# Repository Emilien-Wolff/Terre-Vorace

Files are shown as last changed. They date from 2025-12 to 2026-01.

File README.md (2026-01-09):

# Commande entreprise - solutions d'aération d'un lombricomposteur 🪱
> [!NOTE]
> Un projet dans le cadre de ma deuxième année en école d'ingénieur visant l'élaboration d'une aération d'un lombricomposteur pour préserver les lombrics



## Objectifs

> Améliorer le composteur en le dotant d’un système d’aération efficace permettant la survie des lombrics.

> Permettre une régulation de l’humidité dans l’enceinte du lombricomposteur, sans dépasser un certain seuil.

## Points abordés

 - Gestion de projet : diagramme de Gantt, partage des tâches et planification tout au long du projet
 - Etude thermodynamique : dimensionnement paramétrique de l'installation en fonction de la taille des ouvertures nécessaire, flux, aération forcée ou non, ...
 - Code et montage d'un capteur hygrométrique pour les tests
 - Réalisation : fabrication des solutions techniques et implantation sur lombricomposteurs
 - Rapports au client

## FAQ

#### Qu'est ce que Terre Vorace ?

Terre Vorace est une entreprise française (basée à Nantes) spécialisée dans la gestion des biodéchets pour les structures professionnelles (B2B). Elle propose une solution clé en main de valorisation des biodéchets via le lombricompostage, en installant chez ses clients des composteurs connectés et éco-conçus qui transforment ces déchets en engrais organique utile, tout en assurant un suivi numérique des opérations et des données RSE. L’objectif est de minimiser l’impact environnemental, de réduire les coûts et de faciliter la conformité réglementaire pour les entreprises, écoles ou espaces de coworking qui souhaitent valoriser localement leurs biodéchets.

#### Combien de temps ça vous a pris ?

Le projet a duré 3 mois, de septembre 2025 à  fin novembre 2025

## 🚀 Qui suis-je ?
Je suis actuellement étudiant ingénieur automaticien en deuxième année d'école d'ingénieur à l'école des Mines IMT Atlantique.

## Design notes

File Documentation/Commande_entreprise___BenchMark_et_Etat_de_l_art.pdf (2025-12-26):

X

Benchmark - GROUPE 60
Projet Commande Entreprise - parcours ingénieur A2 FISE

## Projet Commande Entreprise :

## Système d’aération d’un milieu fermé

## en lombricompostage autonome

Destinataires : FRISCOURT François, D’HERBEMONT Arthur Relecteurs : RABIER Valentin

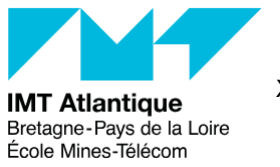
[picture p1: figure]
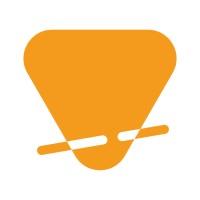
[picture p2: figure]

Date d’édition : 23 octobre 2025 Version : V2

Wolff Emilien

Gerbaud Paul

Albert Louis
Kayser Valentin
Rabier Valentin

Rouyre Sarah
Adam Raphaël

Ribeiro de Assis Nathalia

Tuteur école : D’Herbemont Arthur Tuteur entreprise : Friscours François

IMT Atlantique
Projet Commande Entreprise
Campus de Nantes — IMT Atlantique 4, rue Alfred Kastler — La Chantrerie CS 20722
44307 Nantes Cedex 3
Téléphone : +33 (0)2 51 85 81 00 URL : www.imt-atlantique.fr

Liste des tableaux

### Sommaire

1. Introduction et cahier des charges du projet | 2
2. Benchmark et Etat de l’Art | 4
2.1. Solutions possibles et coût prévisionnel de chacune d’entres elles | | 4
2.1.1. Solution A – Evacuation d’air dans les coins | | 4
2.1.2. Solution B – Tube d’aération unique placé au centre du compost | | 6
2.1.3. Solution C – Ventilation Forcée | | 9
2.1.4. Solution D – Agitation Mécanique | 12
3. Conclusion | 14

### 3.1. Comparaison des solutions entre elles et adéquation avec le cahier des charges | 14

Annexes | 15
Références | 16

### Liste des figures

2.1. Schéma de la solution A | | 4
2.2. Schéma de la solution B | | 6
2.3. Schéma de la solution B | | 9
2.4. Schéma de la solution D | 12

### Liste des tableaux

1.1. Tableau des fonctionnalités, critères, niveaux, flexibilité et priorité pour le projet Terre Vorace.
FP : fonction principale, FS : fonction secondaire, FC : fonction de contrainte | | 3
2.1. Estimation des coûts matière, usinage et membrane pour le tube d’aération latéral, en euros . | 5
2.2. Estimation des coûts matière, usinage et membrane pour le tube d’aération central | | 7
2.3. Estimation des coûts matière, usinage et ventilateur pour la solution C : ventilation forcée. . 10
2.4. Estimation des coûts matière, usinage (solution D) | 13
3.1. Comparaison des solutions A–D selon les critères du cahier des charges | 14
Synthèse de projet | 1/16

## Chapitre 1

# Introduction et cahier des charges du projet

Ce document a pour but de citer les différentes solutions possibles pour aérer efficacement un lombricomposteur. Ces solutions ont été trouvé et établies grâce à des recherches documentaires, et adaptée afin de remplir les exigences établies dans le précédent document. On rappelle ci-après le cahier des charges du projet, ainsi que les objectifs du projet.

En parallèle, une première modélisation physique du système a été effectuée. Le document complet est disponible ci-dessous :
→ Consulter le rapport de modélisation physique du système (PDF)

OBJECTIF

1. Améliorer le composteur en le dotant d’un système d’aération efficace permettant la survie des lombrics.
2. Permettre une régulation de l’humidité dans l’enceinte du lombricomposteur, sans dépasser un certain seuil.

2

Fonction | Critère(s) | Niveau(x) | Flexibilité | Priorité
FP1 – Maintenir un environnement favo-rable aux lombrics | Température interne | ≤ 30◦C (idéal 25°C) | Faible | 1
| Humidité de l’air de la boite | 60–80% | Faible
| Protection contre gel et cha-leur extrême | Tolérance au froid, max 35°C ambiant | Nulle
FP2 – Assurer une ventilation et évacua-tion d’humidité | Débit d’air suffisant | Limiter condensa-tion | Moyenne | 1
| Filtration des odeurs | Aucune odeur à proximité du lombri-composteur (détectable par un nez humain) | Faible
| Étanchéité aux nuisibles | Aucun insecte ni lombric ne passe | Nulle
FS1 – Assurer une autonomie énergé-tique low-tech | Source d’énergie | Piles privi-légiées (pas solaire/piezo) | Moyenne | 2
| Consommation énergétique | Très faible, sys-tème passif fa-vorisé | Forte
FS2 – Assurer un ré-trofit sur des lom-bricomposteurs exis-tants | Simplicité d’installation | Adaptation simple sur lom-bricomposteur existant (-d’1 h) | Moyenne | 1
FC1 – Respecter les contraintes maté-riaux et production | Matériaux | Prototype en bois/imprimé en 3D ; Solu-tion finale en matière recyclé et/ou (métal possible) et/ou bois | Moyenne | 1
| Budget prototypage | ≤ 1000€ | Nulle
FC2 – Assurer une évacuation simple du compost par le tech-nicien | Espace disponible | Aisance d’uti-lisation d’une pelle au sein du lombricom-posteur | Faible | 1
FC3 – Transportabi-lité | Masse totale vide | ≈ 60 kg max | Moyenne | 3

Table 1.1 – Tableau des fonctionnalités, critères, niveaux, flexibilité et priorité pour le projet Terre Vorace. FP : fonction principale, FS : fonction secondaire, FC : fonction de contrainte.

## Chapitre 2

# Benchmark et Etat de l’Art

Cette section présente les différentes solutions analysées dans le cadre du benchmark. Chaque solution est décrite selon des critères afin de permettre une comparaison objective.

### 2.1. Solutions possibles et coût prévisionnel de chacune d’entres elles

### 2.1.1. Solution A – Evacuation d’air dans les coins

■ | Nom de la solution : Evacuation dans les coins
■ | Exigences du CDCF : Toutes
■ | Matériaux envisagés : PVC, Métal (aluminium), Impression 3D

Schéma de la solution :

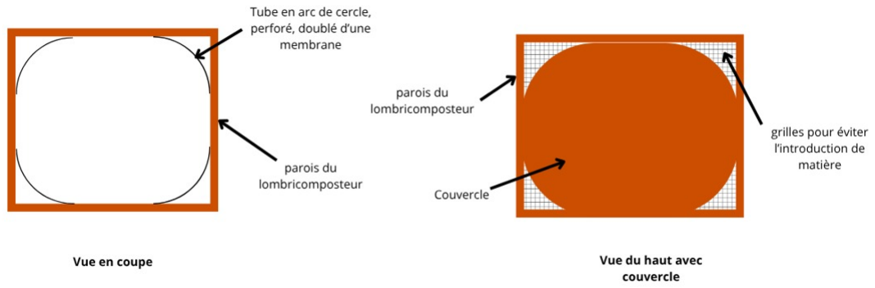
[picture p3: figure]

Figure 2.1 – Schéma de la solution A

Description générale :

Implémentation de tubes en arc de cercle perforés dans les coins du lombricomposteur. Les tubes seront doublés avec une membrane pour éviter le passage des vers ou d’acariens. Le flux d’air principal passera donc dans le coin, entre la paroi du lombricomposteur et le tube. Pour faciliter son passage, le couvercle et le bas du lombricomposteur recouvriront seulement la partie où il y a la matière compostable. Les trous laissés seront recouverts de grillage ou d’une membrane protectrice pour éviter l’introduction de matière à cet endroit.

Fonctionnalités principales :

■ | Gestion du taux d’humidité et de la température dans le composteur
■ | Intégration simple aux composteurs déjà existants
| 4

2.1. Solutions possibles et coût prévisionnel de chacune d’entres elles

Tarification :

On suppose que l’on achètera un tube de 70 cm de long, et de 300 mm de diamètre, que l’on coupe en 4. Chacune des pièces obtenues sera alors insérée dans un coin du lombricomposteur

Dans le cas du PVC :

■ Achat du PVC en magasin de bricolage
■ Usinage par un opérateur (cout de la machine de découpage non inclu)

Dans le cas de l’aluminium recyclé :
Volume de matière nécessaire = Aire de la section de paroi × longueur = π ·(150² −145² )· 0.70 ≈ 0.003245m³
Or la densité de l’aluminium est environ de 2700 kg/m³
Donc la masse d’aluminium nécessaire par tube est de 8.76 kg.
On prend un prix d’aluminium recyclé autour de 1.8 euros par kg (si fabrication d’une cinquantaine de tubes) On ajoute ensuite le coût d’usinage entre 25 à 30 euros par tube.

Dans le cas de l’impression 3D :

Le même volume de matière est nécessaire que dans le cas de l’aluminium. Le prix de la matière est de 25 euros au kilo.
Le cout d’usinage est moindre car on considère la machine déjà amortie, et on usine par quart de tube, donc pas de découpe nécessaire. Les seuls frais associés est celui des employés devant lancés l’imprimante à intervalles réguliers.

Membrane ventilante à coller à l’intérieur du tube

Il faut une membrane microporeuse / perméable à l’air (par exemple membrane PTFE, membrane respirante...) collée ou fixée à l’intérieur du tube pour laisser passer l’air mais limiter le passage de matières solides ou vers. On prend une estimation de coût de membrane à ∼ 0.25 euros/m²
La surface de membrane nécessaire serait l’aire latérale intérieure du tube :
| Amembrane = π d L ≈ π × 0,096 × 0,700 ≈ 0,211 m²

Donc coût membrane :

| Cmembrane ≈ 0,211 × 0,25 = 0.053€

On peut arrondir selon condition de commande, adhésif, découpe, etc. Disons 0,10€ à 0,20€. Coût des matériaux :

Matériau | Coût matière | Usinage estimé | Membrane | Total estimé
PVC | 25€ | 8€ | 0,10€ | 34€
Aluminium | 13€ | 25€ à 30€ | 0,10€ | 40€ à 45€
Impression 3D | 8€ | 5€ à 10€ | 0.10€ | 20€ à 25€

Table 2.1 – Estimation des coûts matière, usinage et membrane pour le tube d’aération latéral, en euros

Avantages :

■ | Facile à mettre en place
■ | Entretien facilité par les angles

Limites :

■ | Etanchéité aux extrémités des tubes à vérifier
■ | Efficacité faible au centre de compost (voir si cette solution s’avère efficace ou non)

### 2.1.2. Solution B – Tube d’aération unique placé au centre du compost

■ | Nom de la Solution [Tube d’aération placé au centre du compost]
■ | Exigences du CDCF : [Toutes]
■ | Matériaux envisagés : PVC, Métal (aluminium, acier), Impression 3D

Schéma de la solution :

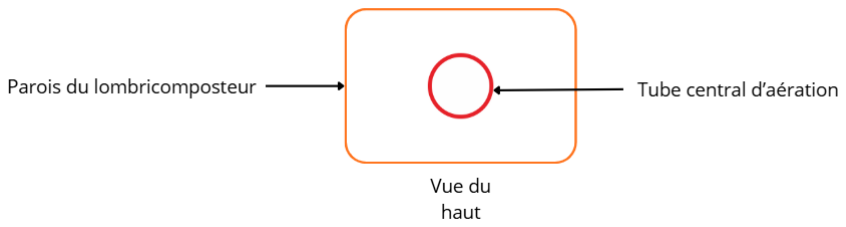
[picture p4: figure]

Figure 2.2 – Schéma de la solution B

Description générale :

Implémentation d’un tube d’aération unique en plein centre du lombricomposteur, muni d’une aération latérale à l’aide de trous percés, ainsi que d’une couche membranique afin d’éviter que les vers ne tombent dans le tuyau ou l’introduction d’acariens. Le tube sera démontable afin de faciliter l’entretien du lombricomposteur, la base restera au fond du composteur est fera la hauteur de la litière des vers. Il sera facilement replaçable (grâce à un système de clip ou de vissage avec la base).

Fonctionnalités principales :

■ | Gestion du taux d’humidité et de la température dans le composteur
■ | Intégration simple aux composteurs déjà existants

Estimation de coût d’un tube d’aération central avec membrane

Hypothèses géométriques

On prend les hypothèses suivantes :

■ | Le tube est de longueur L = 700 mm = 0,700 m.
■ | Diamètre extérieur D = 100 mm = 0,100 m.
■ | Épaisseur de paroi t = 2 mm = 0,002 m.
■ | Diamètre intérieur d = D − 2t = 0,100 − 2 × 0,002 = 0,096 m.

Le volume de matériau est donc :

| V = π · D² − d
| 2
| 4 · L = π · (0,100)² − (0,096)²
| 4 · 0,700 ≈ 0,0004305 m³

On note les densités approximatives :

■ Acier (acier simple) : ρacier = 7 800 kg/m³
■ Aluminium : ρalu = 2 700 kg/m³
■ | PVC rigide : ρPVC = 1 400 kg/m³ (valeur indicative).

Les masses estimées :

macier = ρacier · V ≈ 7 800 × 0,0004305 ≈ 3,36 kg,

malu = 2 700 × 0,0004305 ≈ 1,16 kg,

mPVC = 1 400 × 0,0004305 ≈ 0,60 kg.

Coût matière estimé

Pour le prix unitaire des matières, on prend des estimations raisonnables (à ajuster selon les fournisseurs) :

■ Acier : 1,0 €/kg
■ Aluminium : 2,6 €/kg(valeur souvent citée pour l’aluminium neuf)
■ PVC rigide : 1,5 €/kg

Donc les coûts matière :

Cmatière, acier ≈ 3,36 × 1,0 = 3,36 €

Cmatière, alu ≈ 1,16 × 2,6 = 3,02 €

Cmatière, PVC ≈ 0,60 × 1,5 = 0,90 €

Coût d’usinage / fabrication

On ajoute une estimation pour l’usinage, la découpe, l’assemblage, la finition, selon matériau :

■ Acier : 15€ à 25€
■ Aluminium : 25€ à 30€
■ PVC : 4€ à 8€

Membrane ventilante à coller à l’intérieur du tube

Même calcul que dans la solution A.

Coût total estimé

On met tout ensemble :

Ctotal = Cmatière + Cusinage + Cmembrane.

Matériau | Coût matière | Usinage estimé | Membrane | Total estimé
Acier | ≈ 3,36 € | 15 à 25 € | ∼ 0,10 € | ∼ 18,5 à 28,5 €
Aluminium | ≈ 3,02 € | 25 à 30 € | ∼ 0,10 € | ∼ 28,1 à 33,1 €
PVC | ≈ 0,90 € | 4 à 8 € | ∼ 0,10 € | ∼ 5,0 à 9,0 €

Table 2.2 – Estimation des coûts matière, usinage et membrane pour le tube d’aération central.

Discussion et remarques

■ | Ces estimations dépendent fortement des coûts locaux d’atelier, des quantités, frais de transport, de l’adhésif de membrane, etc.
■ | L’usinage de l’aluminium (soudure ou assemblage) peut être plus coûteux que pour l’acier selon les compétences de l’atelier.
■ | Le PVC est le moins cher mais est moins résistant mécaniquement, et la membrane devra bien adhérer (étanchéité, collage) pour durer dans le temps.
■ | On pourrait envisager une version avec tube plus gros (diamètre extérieur de 120 mm, épaisseur 3 mm), cela augmenterait les coûts proportionnellement au volume.
■ | Si on utilise de l’acier inoxydable, le coût matière pourrait être bien plus élevé.
■ | Le coût de membrane est négligeable comparé au coût matière + usinage dans ces dimensions, mais il faut prévoir adhésifs, découpe, manutention.

Avantages :

■ Aération efficace au centre du compost
■ Entretien facile car le tube est démontable

Limites :

■ | Etanchéité aux extrémités des tubes à vérifier
■ | Etanchéité aux niveau des attaches du tube à vérifier
■ | Perte de volume utile important en fonction de la taille du tube

### 2.1.3. Solution C – Ventilation Forcée

■ | Nom de la Solution [Tube d’aération placé au centre du compost avec aération forcée]
■ | Exigences du CDCF : [Toutes]
■ | Matériaux envisagés : PVC, Métal (aluminium, acier), Impression 3D, ventillateur acheté complet

SCHEMA DE LA SOLUTION :

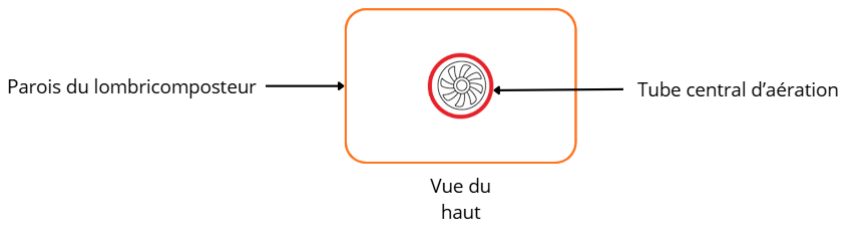
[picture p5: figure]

Figure 2.3 – Schéma de la solution B

Description générale :

La solution consiste à intégrer à nouveau un tube d’aération unique en plein centre du lombricomposteur, muni d’une aération latérale à l’aide de trous percés, ainsi que d’une couche membranique afin d’éviter que les vers ne tombent dans ce même trou. On ajoute un système de ventilation forcée à faible consommation. Ce petit ventilateur, placé sur la partie supérieure ou inférieure du lombricomposteur crée un flux d’air forcé qui augmente l’éfficacité du tube seul.

Fonctionnalités principales :

■ | Gestion du taux d’humidité et de la température dans le composteur
■ | Intégration simple aux composteurs déjà existants

Estimation de coût de la Solution C – Ventilation forcée

Hypothèses géométriques

On prend les mêmes hypothèses géométriques que pour la Solution B afin de garder une cohérence de comparaison :

■ | Longueur du tube L = 700 mm = 0,700 m
■ | Diamètre extérieur D = 100 mm = 0,100 m
■ | Épaisseur de paroi t = 2 mm = 0,002 m
■ | Diamètre intérieur d = D − 2t = 0,100 − 2 × 0,002 = 0,096 m

Le volume du matériau est donc :

| V = π · D² − d
| 2
| 4 · L = π · (0,100)² − (0,096)²
| 4 · 0,700 ≈ 0,0004305 m³

Densités approximatives :
■ Acier (acier simple) : ρacier = 7 800 kg/m³ ■ Aluminium : ρalu = 2 700 kg/m³
■ PVC rigide : ρPVC = 1 400 kg/m³

Masses estimées :

macier = 7 800×0,0004305 ≈ 3,36 kg, | malu = 2 700×0,0004305 ≈ 1,16 kg, | mPVC = 1 400×0,0004305 ≈ 0,60 kg.

Coût matière estimé

Prix unitaires estimés (à affiner selon fournisseurs) :

■ Acier : 1,0 €/kg
■ Aluminium : 2,6 €/kg (valeur moyenne de l’aluminium neuf) ■ PVC rigide : 1,5 €/kg

Donc les coûts matière :

Cmatière, acier ≈ 3,36 × 1,0 = 3,36 €

Cmatière, alu ≈ 1,16 × 2,6 = 3,02 €

Cmatière, PVC ≈ 0,60 × 1,5 = 0,90 €

Coût d’usinage / fabrication

On ajoute une estimation pour la découpe, le perçage, l’assemblage et la fixation du ventilateur selon le matériau :

■ Acier : 8€ à 12€
■ Aluminium : 10€ à 15€
■ PVC : 4€ à 8€

Coût du ventilateur acheté complet

Le ventilateur basse consommation (80–92 mm, 5–12 V, 0,6–1,5 W) constitue l’élément actif principal du système. Prix indicatif selon modèle : 8€ à 15€.

Coût total estimé

Le coût total correspond à la somme du matériau, de l’usinage et du ventilateur :

Ctotal = Cmatière + Cusinage + Cventilateur

Matériau | Coût matière | Usinage estimé | Ventilateur | Total estimé
Acier | ≈ 3,36 € | 8 à 12 € | 8 à 15 € | ∼ 19,4 à 30,4 €
Aluminium | ≈ 3,02 € | 10 à 15 € | 8 à 15 € | ∼ 21,0 à 33,0 €
PVC | ≈ 0,90 € | 4 à 8 € | 8 à 15 € | ∼ 12,9 à 23,9 €

Table 2.3 – Estimation des coûts matière, usinage et ventilateur pour la solution C : ventilation forcée.

Discussion et remarques

■ | Le coût du ventilateur domine légèrement le total (30%–40%), mais reste raisonnable pour un dispositif low-tech (un ventilateur de PC réutilisé pourra faire l’affaire).
■ | L’aluminium offre une bonne durabilité et légèreté, mais un coût d’usinage plus élevé que le PVC.
■ | L’acier est plus robuste mais sensible à la corrosion ; un traitement de surface ou acier inox pourrait être envisagé (hausse de coût).
■ | Le PVC demeure la solution la plus économique, facile à usiner, mais moins résistante mécaniquement à long terme.
■ | Le choix final dépendra de l’équilibre entre coût, robustesse et efficacité thermique/ventilatoire du système.

■ | Le coût global reste modéré : environ 15 € – 35 €, ce qui reste compatible avec une production artisanale ou en petite série.
■ | La conception de cette solution n’est pas encore aboutie, en effet, nous ne savons pas si le tube doit réellement traverser tout le composteur et être ouvert en bas, ce qui mettrait simplement un flux d’air au niveau de l’interface entre le centre du compost et l’extérieur. Nous pourrions également boucher le tube d’un côté et diriger la ventilation de ce côté afin que l’air soit forcé de passer au travers le compost.

Tarification :

Le coût de cette solution dépendra du choix des matériaux et du ventilateur. Il sera forcément plus élevé que les autres solutions.

Avantages :

■ | Flux d’air bien plus conséquent grâce à la ventillation active
■ | Efficacité de ventilation forcément supérieur aux autres solutions

Limites :

■ | Dépendance à une source d’énergie
■ | Entretien régulier du système
■ | Coût élevé
■ | Plus difficile à mettre en place

### 2.1.4. Solution D – Agitation Mécanique

■ | Nom de la Solution [Aérateur de compost manuel]
■ | Exigences du CDCF : [Toutes]
■ | Matériaux envisagés : manivelle ou guidon et tige avec pics (métal et plastique)

SCHEMA DE LA SOLUTION :

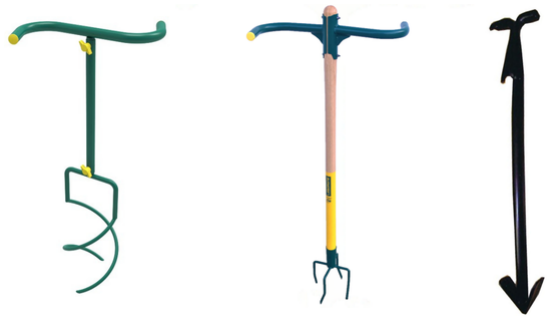
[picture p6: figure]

Figure 2.4 – Schéma de la solution D

Description générale :

La solution consiste à mettre à la disposition de l’utilisateur un aérateur de compost plus ou moins sophistiqué comme ci-dessus. Celui-ci peut alors insérer la fourche dans le compost et le brasser. Ce dispositif, favorise la circulation de l’air dans le compost et l’homogénise. En répartissant plus uniformément la chaleur et l’humidité, cette solution contribue à maintenir des conditions de vie optimales pour les lombrics et favorise le processus de compostage.[1]

Fonctionnalités principales :

Il s’agit de remuer (sans mouvement brusque) le compost environ une fois par mois surtout au milieu du composteur, là où l’aération se fait le moins bien.
■ Activité microbienne : cela permet de répartir les vers et les micro-organismes afin que le compostage se fasse partout et soit donc plus efficace.
■ Favorise la circulation de l’air : cela réduit les mauvaises odeurs qui s’accumulent au centre, optimise le compost qui est un processus aérobie.
■ Réduit l’humidité : l’humidité qui s’accumule au centre peu ainsi s’évacuer et cela permet d’obtenir un meilleur compost.

Tarification :

Ce système étant extérieur au composteur, il n’y a pas besoin de l’intégrer dans le système ce qui coûterait plus cher. De plus, nous pouvons faire le choix d’acheter cet aérateur directement dans le marché ou bien de l’usiner nous-même.

Manivelle et axe rotatif achetés complets :

■ Produit disponible dans le commerce, en acier ou aluminium : Coût unitaire moyen estimé : 10 € à 30 €. [2]
[3] [4]

Usinage

Matériau | Coût matière | Usinage estimé | Total estimé
Acier | ≈ 3 € | 8 à 10 € | ∼ 10 à 15 €
Acier + Bois (manche) | ≈ 4,5 € | 5 à 10 € | ∼ 10 à 15 €
Acier + Plas-tique (guidon) | ≈ 5 € | 8 à 15 € | ∼ 13 à 20 €

Table 2.4 – Estimation des coûts matière, usinage (solution D)

Discussion et remarques

■ | Le coût total reste faible et de nombreuses options sont possibles : tout en acier, guidon en plastique, manche en bois, etc.
■ | Si nous l’usinons, cet aérateur pourrait bien être mis en option à l’achat du lombricomposteur
■ | Il convient de veiller à ne pas perturber les lombrics par une agitation trop fréquente ou trop brusque.

Avantages :

■ Améliore l’aération du compost
■ | Réduit l’humidité
■ | Répartit les vers et les micro-organismes donc favorise le processus
■ | Facile à mettre en place

Limites :

■ | Nécessite une intervention manuelle, ce qui peut réduire la praticité pour l’utilisateur et cela lui rajoute une charge alors qu’il aimerait peut-être que le composteur n’ait pas besoin d’entretien de ce genre
■ | Risque de perturber les lombrics si l’agitation est trop fréquente ou trop intense (d’où la consigne d’une fois par mois avec un brassage délicat)

## Chapitre 3

# Conclusion

### 3.1. Comparaison des solutions entre elles et adéquation avec le cahier des charges

Dans cette section, nous comparons les différentes solutions envisagées en fonction des critères du cahier des charges. Chaque solution est évaluée selon les aspects techniques, économiques et environnementaux, afin de déterminer celle qui répond le mieux aux exigences fixées tout en restant dans une démarche low-tech et de rentabilité.

Critères du cahier des charges | A | B | C | D
FP1 – Maintenir un envi-ronnement favorable aux lombrics | Moyen | Bon | Excellent | Moyen
FP2 – Ventilation et éva-cuation d’humidité | Moyen | Bon | Excellent | Bon
FS1 – Autonomie énergé-tique low-tech | Excellent (passif) | Excellent (passif) | Faible (actif) | Excellent (manuel)
FS2 – Retrofit sur lom-bricomposteurs existants | Bon | Bon | Moyen | Excellent
FC1 – Contraintes maté-riaux et budget | Bon (20–50 €) | Très Bon (15–30 €) | Moyen (15–35 €) | Excellent (10-20 €)
FC2 – Facilité d’utilisa-tion / maintenance | Bon | Bon | Moyen | Moyen
FC3 – Transportabilité / masse | Bon | Bon | Moyen | Bon

Table 3.1 – Comparaison des solutions A–D selon les critères du cahier des charges.

Analyse comparative :
— La solution A (tubes d’aération dans les coins) est simple, économique et totalement passive. Elle respecte bien le cahier des charges low-tech, mais son efficacité reste limitée au centre du compost, là ou réside le souci principal.
— La solution B (tube central) apporte une aération plus homogène, reste peu coûteuse et facile à intégrer. Elle combine donc bon rapport efficacité/coût.
— La solution C (ventilation forcée) est la plus performante en termes de régulation thermique et d’humidité, mais nécessite une source d’énergie et augmente les coûts ainsi que la complexité. — La solution D (agitation mécanique) est la plus low-tech et la moins coûteuse, mais dépend d’une action humaine régulière, ce qui réduit sa praticité.
Autres options : Il est tout à fait possibles de combiner des solutions pour trouver le système parfait. (par exemple A et D, B ou C et D, A et B ou C)

14

### Annexes

15

# Bibliographie

[1] Conseil | pour | l’utilisation | d’aérateur | de | compost | : | https://plus2vers.com/fr/
faut-il-remuer-son-lombricompost-voici-nos-conseils/ (https://plus2vers.com/fr/faut-il-remuer-son-lombricompost-voici-nos-conseils/)
[2] Aérateur | du | marché | 1 | : | https://www.leborgne.fr/outils-professionnels/
griffes-cultivateurs-et-tire-ligne/aerocompost-naturovert-.html (https://www.leborgne.fr/outils-professionnels/griffes-cultivateurs-et-tire-ligne/aerocompost-naturovert-.html)
[3] Aérateur | du | marché | 2 | : | https://www.leborgne.fr/outils-professionnels/
biogrif-et-rotogrif-/rotogrif-4-dents.html (https://www.leborgne.fr/outils-professionnels/biogrif-et-rotogrif-/rotogrif-4-dents.html)
[4] Aérateur | du | marché | 3 | : | https://www.signals.fr/aerateur-compost.html?
utm_source=google&utm_medium=cpc&utm_campaign=FRA%20%7C%7C%20FR%20%7C% 7C%20PLA%20%7C%7C%20NB%20%7C%7C%20%7B99%20-%20All%20Products%7D%20-% 20%2802%20-%20PMax%29%20%7C%7C%20GEN%20%7C%7C%2002GG&gad_source=1&gad_ campaignid=18179579717&gbraid=0AAAAADk7CR5YTOEzql7mVgGzMTyGLlM8F&gclid= Cj0KCQjw9czHBhCyARIsAFZlN8SeFIy07Q4n9GQB0IovYUHA1FI06HDpiHcjfzl652mXyaN7IRvRNxIaArP3EALw_ wcB#10MFM100 (https://www.signals.fr/aerateur-compost.html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)

16

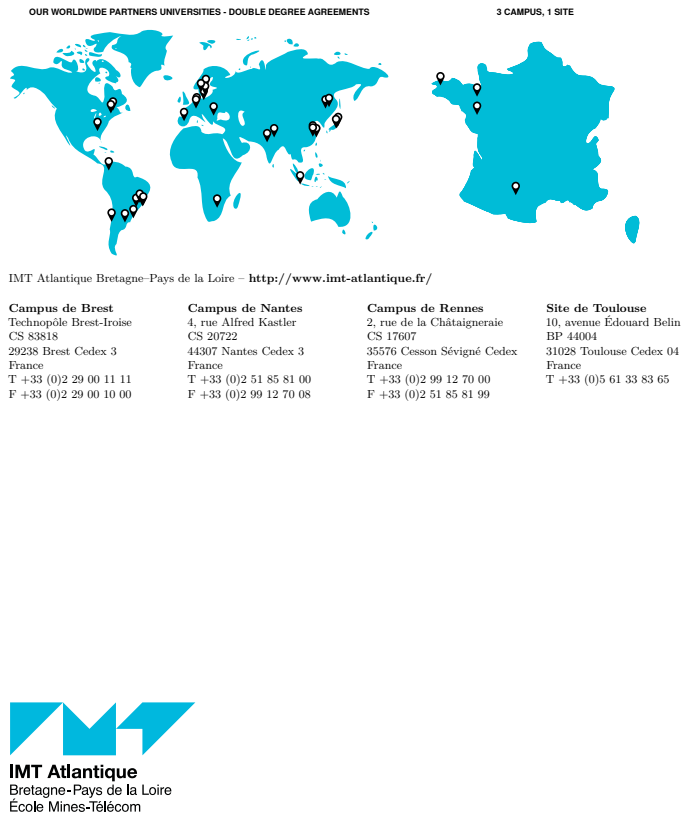
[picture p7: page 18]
OUR WORLDWIDE PARTNERS UNIVERSITIES - DOUBLE DEGREE AGREEMENTS; 3 CAMPUS, 1 SITE; Campus de Brest Technopôle Brest-Iroise CS 83818 29238 Brest Cedex 3 France T +33 (0)2 29 00 11 11 F +33 (0)2 29 00 10 00; Campus de Nantes 4, rue Alfred Kastler CS 20722 44307 Nantes Cedex 3 France T +33 (0)2 51 85 81 00 F +33 (0)2 99 12 70 08

IMT Atlantique Bretagne–Pays de la Loire – http://www.imt-atlantique.fr/

Campus de Rennes
2, rue de la Châtaigneraie
35576 Cesson Sévigné Cedex
France

Site de Toulouse
10, avenue Édouard Belin
31028 Toulouse Cedex 04

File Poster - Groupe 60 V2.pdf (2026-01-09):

Optimisation de l’aération d’un lombricomposteur Une solution simple, durable et efficace pour Terre Vorace

### Contexte

m

ሶ
air

min
=

Q

ሶ
gen −

∆T
R
cp,air∆T

=

30 −

9
0,269
1005 × 9

≈

30 − 33,4
9045

< 0

TITRE DE LA PRÉSENTATION 08 /01/20 26 | 1

### Conception

Nous avons conçu 3 solutions :

A. un système d’évacuation de l’air par les coins

du composteur ;

B. un système d’évacuation de l’air par un tube

central ;

C. une solution manuelle par aérateur de compost.

La conception a été réalisée en CAO afin de :

- visualiser les solutions ;
- adapter les pièces aux composteurs existants ;
- faciliter la fabrication des prototypes.

### Réalisation

Les principales étapes ont été :

- l’usinage de pièces en bois et en PVC ;
- l’impression 3D de pièces sur mesure ;
- l’assemblage | et | l’intégration | des | systèmes

d’aération sur les composteurs.

Ces prototypes permettront de réaliser des tests afin de valider les solutions proposées et de les commercialiser.

Emilien Wolff
Paul Gerbaud
Louis Albert
Valentin Rabier
Valentin Kayser
Raphaël Adam
Nathalia Ribeiro de Assis
Sarah Rouyre

Terre Vorace est une micro-entreprise qui propose des solutions de lombricomposteurs pour particuliers et professionnels. Notre rôle a été :
1. D’améliorer le lombricomposteur en le dotant d'un système d'aération efficace permettant la survie des lombrics.
2. De permettre une régulation de l'humidité dans l'enceinte du lombricomposteur, sans dépasser un certain seuil.

François Friscourt

Tuteur école

Arthur d’Herbemont
Thèmes

Conception mécanique
Usinage et fabrications
de pièces
Prototypage et bricolage
Benchmark et état de
l’art
Éco-conception
Transfert thermique
Modélisation physique

Site de Terre
Vorace

Adresse mail

projet-commande-terrevorace-60-request@imtatlantique.fr

Prototype final (A) du lombricomposteur avec évacuation dans les coins

Captures d’écran des modélisations sur Fusion 360

Tuteur entreprise

Auteurs

Partie prenante

L’équation ci-dessus nous a permis d’identifier que nous n’avons pas besoin d’évacuer la température du lombricomposteur mais uniquement de créer un flux d’air.
Nous avons :
- étudié les conditions nécessaires à la survie des lombrics ;
- réalisé une modélisation thermique du composteur ;

Ainsi, l’aération est principalement nécessaire pour : évacuer l’excès d’humidité et limiter les odeurs et la condensation

### Dimensionnement

A B

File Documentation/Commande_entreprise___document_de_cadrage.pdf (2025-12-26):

X

Synthèse de Projet - GROUPE 60
Projet Commande Entreprise - parcours ingénieur A2 FISE

## Projet Commande Entreprise :

## Système d’aération d’un milieu fermé

## en lombricompostage autonome

Destinataires : FRISCOURT François, D’HERBEMONT Arthur Relecteurs : RABIER Valentin


Date d’édition : 29 octobre 2025 Version : V2

Wolff Emilien

Gerbaud Paul

Albert Louis
Kayser Valentin
Rabier Valentin

Rouyre Sarah
Adam Raphaël

Ribeiro de Assis Nathalia

Tuteur école : D’Herbemont Arthur Tuteur entreprise : Friscours François

IMT Atlantique
Projet Commande Entreprise
Campus de Nantes — IMT Atlantique 4, rue Alfred Kastler — La Chantrerie CS 20722
44307 Nantes Cedex 3
Téléphone : +33 (0)2 51 85 81 00 URL : www.imt-atlantique.fr

Liste des tableaux

## Sommaire

Préambule | 2
1. Présentation du projet et cahier des charges | 3
1.1. Contexte | | 3
1.1.1. Contexte du projet | | 3
1.1.2. Enjeu pour l’entreprise | | 4
1.1.3. L’équipe | | 4
1.2. Introduction au projet ingénieur | | 5
1.2.1. Plan d’attaque | | 5
1.2.2. Documentation et recherches initiales | | 5
1.2.3. Cahier des charges du projet | | 7
2. Organisation | 9
2.1. Tableau des livrables et Découpage en Phase du Projet | | 9

### 2.2. Organigramme WBS du projet | 10

### 2.3. Diagramme de Gantt du projet | 10

### 2.4. Communication | 11

2.4.1. Moyens de communication internes | 11
2.4.2. Moyens de communication externe | 11
3. Conclusion | 12
Annexes | 13
Annexe 1 – Contrat de projet | 14
Références | 17

## Liste des figures

1.1. Schéma du lombricomposteur sans système d’aération | | 3
1.2. Lombricomposteur Terre Vorace | | 4
1.3. Lombricomposteur à plateau empilés | | 5
1.4. Lombrics Eisenia fetida | | 5
1.5. Risques | | 7
1.6. Cadre Légal | | 7
2.1. Organigramme du projet Terre Vorace | 10
2.2. Diagramme de Gantt | 11

## Liste des tableaux

1.1. Caractéristiques techniques du lombricomposteur Terre Vorace | 6
1.2. Tableau des fonctionnalités, critères, niveaux, flexibilité et priorité pour le projet Terre Vorace.
FP : fonction principale, FS : fonction secondaire, FC : fonction de contrainte | 8
2.1. Planning prévisionnel des semaines à venir | 10
3.1. Tableau des actions à court terme individuelles | 12
Synthèse de projet | 1/17

# Préambule

Dans le cadre de notre formation en tant qu’ingénieur généraliste à IMT Atlantique, les étudiants sont amenés à réaliser un projet spécifique, en lien avec une entreprise / startup, qui initie au monde professionnel et aux exigences d’un client.

Le groupe 60, composé de Raphaël, Emilien, Louis, Valentin R., Valentin K., Nathalia, Paul et Sarah travaille avec l’entreprise Terre Vorace, incubée à IMT Atlantique, et qui propose une solution innovante de lombricompostage connecté pour revaloriser ses biodéchets [1].

Après une première réunion de lancement de projet le lundi 22 septembre avec le client, François Friscourt, fondateur et dirigeant de Terre Vorace, et une discussion autour des exigences, objectifs, attentes et livrables, ce document est là pour cadrer le projet et poser à la fois le cahier des charges détaillé du projet au Chapitre 1, mais aussi notre stratégie organisationnelle au Chapitre 2.

L’équipe 60

2

## Chapitre 1

# Présentation du projet et cahier des charges

## 1.1. Contexte

### 1.1.1. Contexte du projet

Un lombricomposteur est un système qui utilise des vers rouges pour transformer les déchets organiques (épluchures, marc de café, carton. . .) en un engrais naturel appelé lombricompost, ainsi qu’en jus fertilisant nommé lombrithé. Les déchets sont en général placés dans des plateaux aérés et humides, permettant de séparer des étages : au fil du temps, les vers montent vers les nouveaux déchets tandis que le compost mûr reste en bas, prêt à être récolté.

Les lombricomposteurs de Terre Vorace ne sont pas constitués de plateaux, mais d’une cuve principale aérée.

Il permet de maintenir une humidité optimale et d’éviter la surchauffe, qui tuerait les vers.

Voici un schéma du lombricomposteur dans lequel sera implémenté notre système de ventilation.

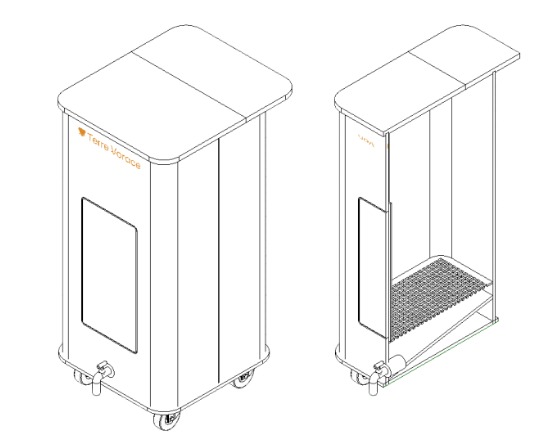
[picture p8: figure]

Figure 1.1 – Schéma du lombricomposteur sans système d’aération

3

1.1. Contexte

Suite à notre première réunion, nous avons relevé quelques caractéristiques du système, qui nous paraissent importantes dans le cadre de notre modification technique.

- construit en plastique recyclé (le système de ventilation doit idéalement
pouvoir être implémenté sur les anciennes versions, en bois lazuré)
- l’excès de liquide est évacué grâce au robinet, situé en bas du composteur. Un grillage à poule recouvert d’un filtre permet de retenir la matière compostée au dessus de l’espace réservé au liquide (bois troué recouvert de géotextile pour l’ancienne version)
- Les déchets peuvent être ajoutés jusqu’au couvercle
- les vers peuvent se déplacer dans toute matière compostable
- le compost est régulièrement vidé manuellement par un opérateur
- le système d’aération actuel est constitué de diverses ouvertures audessus et sur les côtés du lombricomposteur. Ces ouvertures sont recouvertes de membranes en maille en acier inoxydable afin d’éviter l’escapade des vers. Cette membrane est doublée d’un filtre à charbon actif, permettant d’éviter les odeurs
- Le poids actuel des anciennes versions du lombricomposteur (version en bois lasuré) est de 20 kg à vide, et jusqu’à 200 kg plein.

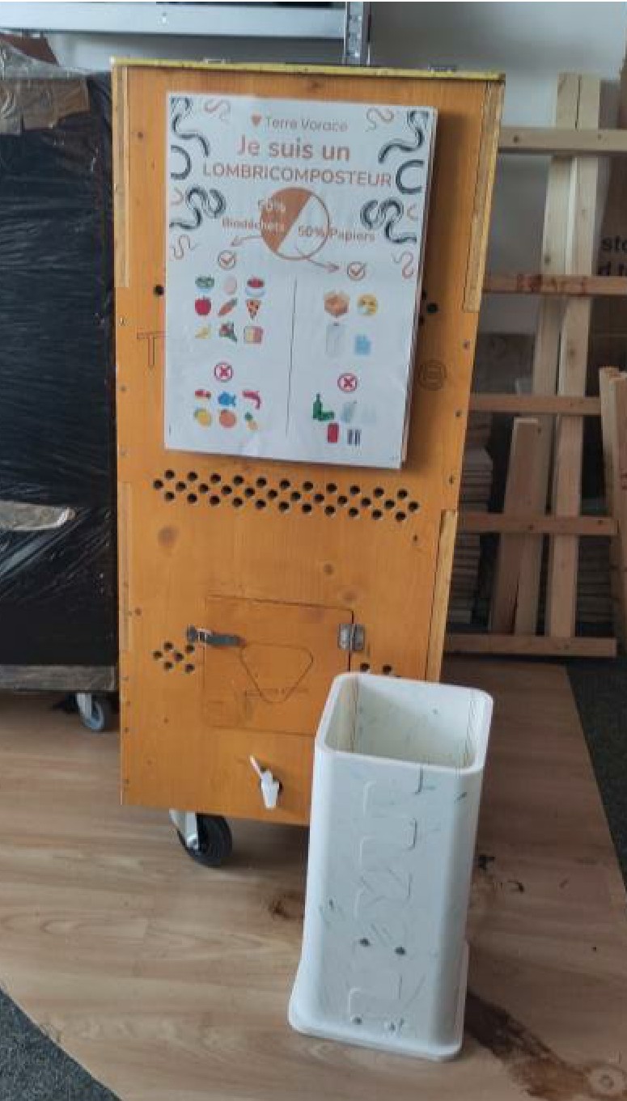
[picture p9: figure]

Figure 1.2 –
Lombricomposteur Terre Vorace

### 1.1.2. Enjeu pour l’entreprise

Les lombricomposteurs actuellement utilisés par l’entreprise n’ont pas de système de régulation de la température. Dans certaines situations, les conditions peuvent donc entraîner la mort des vers.

L’enjeu de ce système d’aération serait de permettre de maintenir l’intérieur du composteur dans des conditions permettant la survie des vers.

Le but final de l’entreprise étant de louer 400 composteurs, ce système devrait permettre d’alléger la fréquence des maintenances nécessaires.

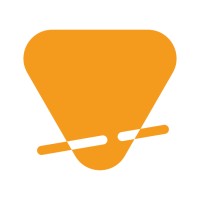
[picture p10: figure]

### 1.1.3. L’équipe

L’équipe est composée de 8 personnes. Voici la répartition des rôles (encadrée par un contrat de projet présenté en Annexe 1) :

→ Emilien WOLFF, chef de projet. Il dispose d’une expérience riche en conception, mécanique et électronique, et en fabrication, additive ou soustractive. Il a déjà été à la tête d’un projet ambitieux en première année (Projet Abysse). (https://github.com/Equipe-Pronto/Pronto-Abysse)

→ Paul GERBAUD, responsable de la communication externe. Président de la Junior-Entreprise de l’école, il a de solides compétences en projet de groupes.

→ Louis ALBERT, responsable de la communication interne. Secrétaire Général de la Junior-Entreprise de l’école, il coordonne l’organisation interne et développe des compétences en gestion d’équipe.

→ Nathalia RIBEIRO DE ASSIS, responsable de la documentation

→ Raphaël ADAM, responsable de la documentation

→ Valentin KAYSER, membre actif. A déjà réalisé de multiples projets en groupe ou en solo. Dispose d’un bon sens physique et de connaissances en électronique et mécanique. Il a hâte de réaliser un projet tangible.

→ Valentin RABIER, membre actif. Son expérience en qualité des rendus à la Junior lui a permis de développer une bonne maîtrise des outils de présentation, qu’il souhaite mettre au service de l’équipe et compléter par de nouvelles compétences techniques.

→ Sarah ROUYRE, membre actif. Possède une expérience en projet, et des compétences transversales lui permettant d’effectuer des tâches très différentes. Elle a envie d’apprendre de nouveaux savoirs-faire dans ce projet.

1.2. Introduction au projet ingénieur

## 1.2. Introduction au projet ingénieur

### 1.2.1. Plan d’attaque

Nous commençons par définir précisément les attendus de l’entreprise et le contexte du projet en Section 1.2.3. Une fois que cela est fait, nous ferons un état de l’art, afin de connaître les solutions déjà existantes.
Nous proposerons ensuite plusieurs solutions (incluant également des alternatives de plusieurs matériaux et les différences de coût, d’efficacité et d’impact associés), que nous exposerons au tuteur entreprise.
Nous construirons ensuite un prototype de notre solution.

### 1.2.2. Documentation et recherches initiales

Dans le cadre du lancement du projet, nous avons entrepris une phase de documentation et de recherches initiales afin de mieux comprendre les enjeux techniques et scientifiques liés au développement d’un système d’aération pour lombricomposteur. Cette démarche a consisté, d’une part, à analyser les besoins exprimés par le client et, d’autre part, à explorer les solutions déjà existantes sur le marché ou dans la littérature technique.

### 1.2.2.1. Types de Lombricompostage

Voici différentes méthodes de lombricompostage utilisées par des particuliers ou des entreprises :

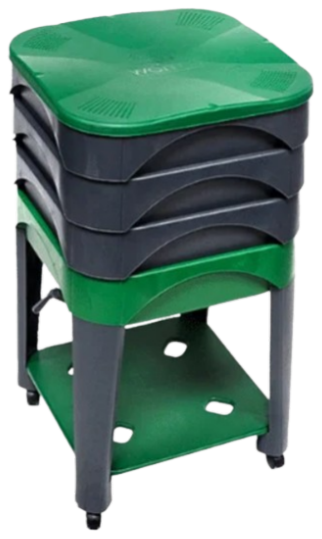
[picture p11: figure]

Figure 1.3 –
Lombricomposteur à plateau empilés
- Plateaux Empilés : on alimente par le haut ; les vers montent vers la nourriture, on récolte l’étage ancien [2]
- Flow-Through continu "CTF" : on nourrit en continu par le haut, on récolte en dessous [3]. C’est la technique utilisée par Terre Vorace
- Enterré-aéré : le bac est enterré dans une jardinière/plate-bande. Les vers vivent à la fois dans le compartiment et dans la terre autour [4].
- CFT industriels : Le bac est alimenté en continu par le haut, et le compost mûr est récolté par le bas automatiquement. Les vers migrent naturellement vers les déchets frais, ce qui permet une production régulière et sans tri fastidieux [5].

### 1.2.2.2. Conditions de vie des lombrics

Les lombrics dans un lombricomposteur vivent selon certaines conditions. Dans cette sous-section, nous les listerons.

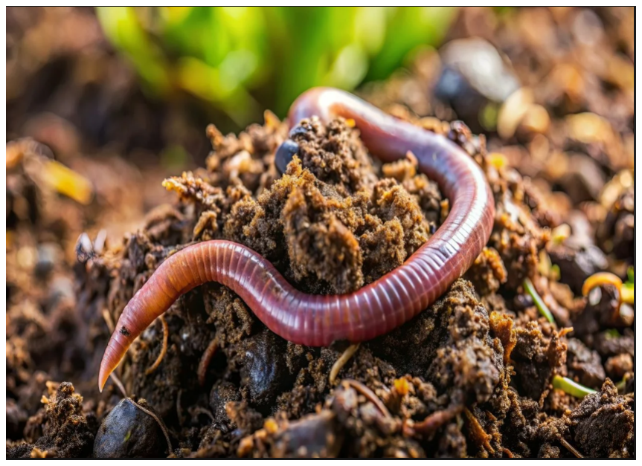
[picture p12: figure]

Figure 1.4 – Lombrics Eisenia fetida

- Photophobie : Les lombrics fuient la lumière ; c’est pourquoi l’environnement de compostage est clos.
- Température : le fonctionnement correct du lombricomposteur se situe entre 10 ◦C et 30 ◦C. Au-delà, la mortalité grimpe et le rendement chute. Il faut donc viser une température strictement inférieure à 30 ◦C en toute circonstance.
- Humidité : l’humidité du milieu doit être comprise entre 60 % à 80 % afin d’éviter de noyer les vers comme de les dessécher.
- pH : idéalement légèrement acide ; un pH compris entre 5.5 et 7 est cohérent.
- Alimentation : les lombrics se nourrissent de déchets végétaux ; des coquilles d’œufs broyées apportent du calcium [6].

1.2. Introduction au projet ingénieur

### 1.2.2.3. Processus de Compostage

La réaction de compostage est une réaction bio-chimique d’oxydo-réduction exothermique, il s’agit d’un processus naturel de décomposition de la matière organique par des micro-organismes [7]. Il en existe deux types, le compostage aérobie et anaérobie, soit avec ou sans oxygène ; or ici, les vers ayant besoin d’oxygène pour survivre, nous ne nous intéressons pas au cas anaérobie. Il est difficile de définir simplement cette réaction chimique, mais le compostage aérobie peut se modéliser grossièrement par :

Matière organique + O2 −→ CO2 + H2O + NH3 + Humus + Chaleur

Les vers de compost agissent sur les éléments encore peu décomposés. Ils permettent la présence de leurs excréments dans le mélange de débris organique ce qui constitue un milieu idéal pour les micro-organismes.

### 1.2.2.4. Types de ventilations existantes

La ventilation représente un élément majeur pour le lombricomposteur. En effet, le lombricompostage est un processus dit aérobie, c’est-à-dire qu’il a besoin d’oxygène pour fonctionner.
En tant que solution simple à réaliser, il est recommandé de percer des trous 5 − 10mm à la base du lombricomposteur.

Deux solutions principales se présentent à nous :

- Une ventilation forcée, qui intègre un tube de PVC faisant office de gaine au bout duquel se trouve un ventilateur. La gaine est percée latéralement.
- Une ventilation naturelle, sans ventilateur, donc sans besoin d’alimentation en électricité qui créé un courant d’air entre la surface haute et basse.

### 1.2.2.5. Constantes du système

Voici les constantes spécifiques au lombricomposteur de Terre Vorace

Caractéristique | Valeurs / Données
Poids du composteur | - ∼ 20 kg à vide (ancienne version bois lazuré) - jusqu’à 200 kg en charge maximale
Population de vers rouges | - Masse critique : 0, 5−2 kg de vers par composteur
Constante de la tourbe humide | - Conductivité thermique : ≃ 0, 1 − 0, 3W·m⁻¹ · K⁻¹ - Résistivité : 5Ω/m
Production de compost | - Biodéchets traités : 100−150 kg/an par foyer - Ratio de transformation : ∼ 30% en compost solide - Volume de lombrithé : 0, 1−0, 3 L/kg de déchets
Aération nécessaire | - Consommation O2 : 0, 5−1 L O2/h/kg de vers - Teneur minimale en O2 : > 10% dans le substrat
Dimensions du composteur (Terre Vorace) | - Volume utile : 80−100 L - Hauteur : ∼ 70 cm - Diamètre moyen : ∼ 45 cm

Table 1.1 – Caractéristiques techniques du lombricomposteur Terre Vorace

1.2. Introduction au projet ingénieur

### 1.2.2.6. Risques

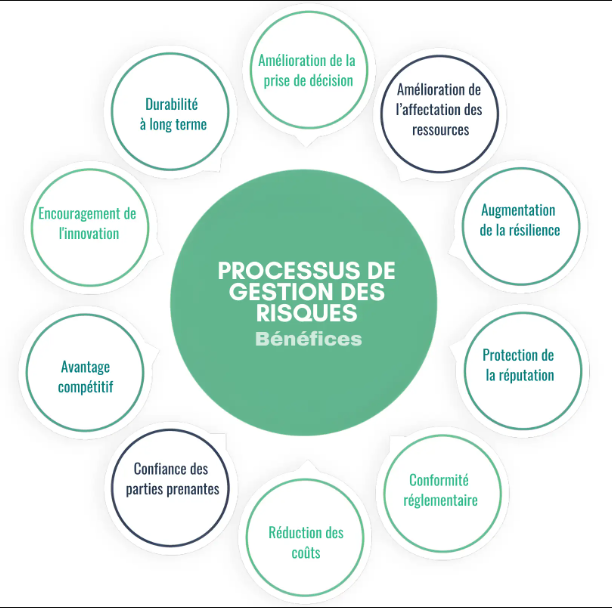
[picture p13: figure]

Figure 1.5 – Risques

- Surchauffe du composteur : activité microbienne qui élève la température au-delà de 30 °C (stress) et 35 °C (mortalité des lombrics) [8].
- Excès d’humidité : au-delà de 80 %, apparition de conditions anaérobies, baisse de la qualité du compost et prolifération d’insectes nuisibles [9].
- Fuite des lombrics : risque si les ouvertures ne sont pas protégées par des barrières adaptées (géotextile, grilles) [10].
- Intrusion de nuisibles : moucherons, moustiques et acariens pouvant perturber le processus [11].
- Émanations d’odeurs : problème d’acceptabilité en intérieur en l’absence de filtration (charbon actif, biochar) [12].
- Fragilité structurelle : le composteur doit supporter environ 60 kg de matière sans casse ni déformation.

(

### 1.2.2.7. Cadre et réglementation

Dans le cadre de ce projet, il convient de préciser que notre activité se limite à l’amélioration du lombricomposteur. Ainsi, les normes relatives au compost (comme la NF U 44-051 ou la NF U 44-095) et les obligations liées au tri des biodéchets (loi AGEC) ne sont pas directement applicables à notre mission.

Choix des matériaux :
- Éviter les substances nocives dans le bois ou
platisque de la boîte. (conformité au règlement REACH). Privilégier des matériaux sûrs en contact avec la matière organique (plastiques conformes au règlement (UE) n°10/2011 pour le contact alimentaire et bois non traité chimiquement).

Durabilité et impact environnemental :

- Favoriser la recyclabilité ou la biodégradabilité des matériaux (norme NF EN 13432) et favoriser le low-tech.

Utilisation des vers :

- Seules des espèces de lombrics non protégées sont concernées par des obligations réglementaires.

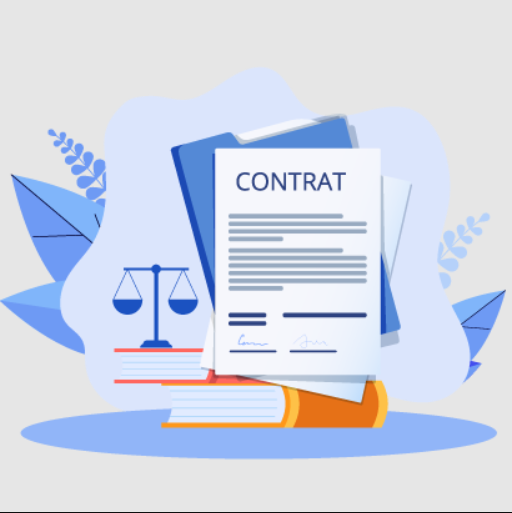
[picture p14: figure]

Figure 1.6 – Cadre Légal

### 1.2.3. Cahier des charges du projet

A partir de toutes ces recherches documentaires, nous pouvons alors établir notre objectif, qui va nous guider tout au long de la conception et de la fabrication du système d’aération :

OBJECTIF

1. Améliorer le composteur en le dotant d’un système d’aération efficace permettant la survie des lombrics.
2. Permettre une régulation de l’humidité dans l’enceinte du lombricomposteur, sans dépasser un certain seuil.

1.2. Introduction au projet ingénieur
Fonction | Critère(s) | Niveau(x) | Flexibilité | Priorité
FP1 – Maintenir un environnement favo-rable aux lombrics | Température interne | ≤ 30◦C (idéal 25°C) | Faible | 1
| Humidité de l’air de la boite | 60–80% | Faible
| Protection contre gel et cha-leur extrême | Tolérance au froid, max 35°C ambiant | Nulle
FP2 – Assurer une ventilation et évacua-tion d’humidité | Débit d’air suffisant | Limiter condensa-tion | Moyenne | 1
| Filtration des odeurs | Aucune odeur à proximité du lombri-composteur (détectable par un nez humain) | Faible
| Étanchéité aux nuisibles | Aucun insecte ni lombric ne passe | Nulle
FS1 – Assurer une autonomie énergé-tique low-tech | Source d’énergie | Piles privi-légiées (pas solaire/piezo) | Moyenne | 2
| Consommation énergétique | Très faible, sys-tème passif fa-vorisé | Forte
FS2 – Assurer un ré-trofit sur des lom-bricomposteurs exis-tants | Simplicité d’installation | Adaptation simple sur lom-bricomposteur existant (-d’1 h) | Moyenne | 1
FC1 – Respecter les contraintes maté-riaux et production | Matériaux | Prototype en bois/imprimé en 3D ; Solu-tion finale en matière recyclé et/ou (métal possible) et/ou bois | Moyenne | 1
| Budget prototypage | ≤ 1000€ | Nulle
FC2 – Assurer une évacuation simple du compost par le tech-nicien | Espace disponible | Aisance d’uti-lisation d’une pelle au sein du lombricom-posteur | Faible | 1
FC3 – Transportabi-lité | Masse totale vide | ≈ 60 kg max | Moyenne | 3

Table 1.2 – Tableau des fonctionnalités, critères, niveaux, flexibilité et priorité pour le projet Terre Vorace. FP : fonction principale, FS : fonction secondaire, FC : fonction de contrainte.

## Chapitre 2

# Organisation

POINTS ORGANISATIONNELS

1. Fréquence et planification : 2 réunions par mois avec le client (jeudi ou vendredi), en plus des suivis réguliers avec le tuteur de l’école et le référent technique.
2. Communication rapide : groupe WhatsApp dédié pour poser des questions, demander des informations et valider des achats.
3. Partage de documents : utilisation d’une plateforme collaborative de l’école (Partage) pour centraliser le cahier des charges, les comptes rendus de réunion et les rapports.
4. Organisation : dossiers bien structurés, incluant les fichiers Fusion 360 et les codes.
5. Qualité des livrables : chaque document est relu collectivement, en particulier ceux produits avec l’aide de l’IA.

## 2.1. Tableau des livrables et Découpage en Phase du Projet

Nous détaillons dans cette section l’intégralité des différentes phases du projet ainsi que leurs dates associées et les livrables qui seront rendus à la clôture de chacune de ces phases.
Le Projet sera donc découpé en 4 phases :
- Phase 1 : Cadrage du projet
Durant cette phase, l’objectif sera de fournir le « document de cadrage du projet », qui constitue le récapitulatif des attendus de la mission. À l’issue de cette phase, un document de cadrage sera remis : cahier des charges du projet, présentation générale de l’équipe, enjeux pour l’entreprise, état actuel du projet et méthodologie de communication avec le client.

### 15 Septembre – 02 Octobre

- Phase 2 : Benchmark et État de l’art
L’objectif de cette phase sera de réaliser le benchmark le plus complet possible des solutions existantes d’aération de lombricomposteurs, qu’ils soient à étage ou d’un seul bloc. Nous étudierons les méthodes d’aération possibles, leurs adaptations, ainsi que les matériaux envisageables pour le développement de chaque solution. À l’issue de cette phase, un document complet contenant le benchmark et l’état de l’art sera remis au client.

### 02 Octobre – 22 Octobre

- Phase 3 : Prototypage du système d’aération
Cette phase sera la première phase technique. À partir des ressources collectées lors des phases précédentes, nous développerons un prototype viable et fonctionnel répondant aux critères du cahier des charges pour le dimensionnement du système d’aération. À l’issue de cette phase, nous remettrons un prototype fonctionnel au client.

### 22 Octobre – 06 Décembre

9

2.3. Diagramme de Gantt du projet
- Phase 4 : Tests unitaires et Recette
Cette phase se divisera en deux parties :

— Tests nécessaires à la vérification du fonctionnement du prototype, ainsi que tests unitaires pour les systèmes d’aération réels dérivés du prototype.
— Établissement de la recette du projet.

Livrables : livrable des tests unitaires + recette de projet.

### 06 Décembre – 19 Décembre

## Planning prévisionnel

Dénomination | Semaines (15 Septembre – 19 Décembre)
| S1 | S2 | S3 | S4 | S5 | S6 | S7 | S8 | S9 | S10 | S11 | S12 | S13
Phase 1
Cadrage du projet
Phase 2 Benchmark et État de l’art

Phase 3 Prototypage du système d’aération

Phase 4 Tests unitaires et recette

Table 2.1 – Planning prévisionnel des semaines à venir

Des sessions de tests seront réalisées lors de la Phase 3 en parallèle du prototypage afin d’optimiser le temps.

## 2.2. Organigramme WBS du projet

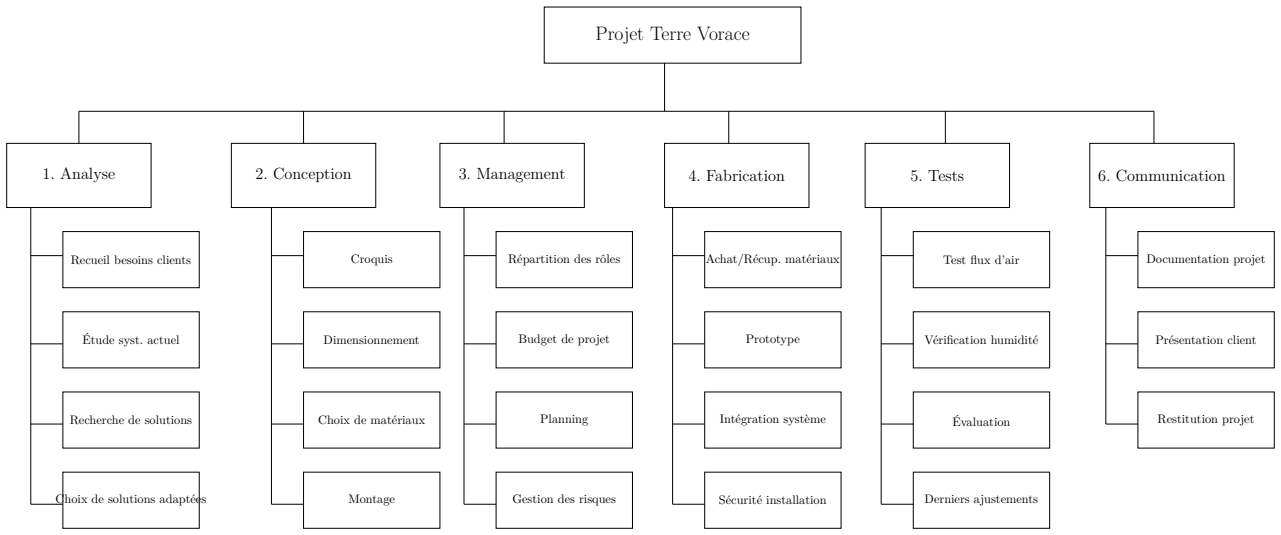
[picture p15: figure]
Projet Terre Vorace; 1. Analyse; Recueil besoins clients; Étude syst. actuel; Recherche de solutions; Choix de solutions adaptées; 2. Conception; Croquis; Dimensionnement; Choix de matériaux; Montage; 3. Management; Répartition des rôles; Budget de projet; Planning; Gestion des risques; 4. Fabrication; Achat/Récup. matériaux; Prototype; Intégration système; Sécurité installation; 5. Tests; Test flux d’air; Vérification humidité; Évaluation; Derniers ajustements; 6. Communication; Documentation projet; Présentation client; Restitution projet

Figure 2.1 – Organigramme du projet Terre Vorace

## 2.3. Diagramme de Gantt du projet

A partir de toutes ces informations, et en prenant en compte la demande du client nous construisons le diagramme de Gantt suivant :

2.4. Communication
Nom | Date de début | Date de fin
Préparation document cadrage projet | 15/09/2025 | 02/10/2025
etat de l'art | 03/10/2025 | 21/10/2025
recherche d'études scientifiques | 03/10/2025 | 21/10/2025
rédaction du rapport | 03/10/2025 | 21/10/2025
étude de plusieurs solutions | 22/10/2025 | 04/11/2025
schéma précis des systèmes envisagés | 22/10/2025 | 04/11/2025
étude avantages/inconvénients de chaque système | 22/10/2025 | 04/11/2025
vérification que les solutions rép... | 22/10/2025 | 28/10/2025
Préparation document de revue | 26/10/2025 | 01/11/2025
etude des materiaux pour la solution retenu | 05/11/2025 | 19/11/2025
etude des matériaux pour la solution réelle | 05/11/2025 | 19/11/2025
étude des matériaux pour le prototype | 05/11/2025 | 11/11/2025
fabrication du prototype | 12/11/2025 | 09/12/2025
conception du prototype | 12/11/2025 | 02/12/2025
test de la solution en milieu réel | 03/12/2025 | 09/12/2025
Préparation recette avec client et le tuteur | 10/12/2025 | 18/12/2025
Retour d'expérience | 19/12/2025 | 19/12/2025
vacances | 20/12/2025 | 02/01/2026
Poster v1 (livrable) | 03/01/2026 | 09/01/2026
Poster Vfinale (livrable) | 10/01/2026 | 16/01/2026

Figure 2.2 – Diagramme de Gantt

## 2.4. Communication

### 2.4.1. Moyens de communication internes

Au sein de l’équipe, il était important dès les premières séances d’établir des moyens de communication clairs, au sein du groupe et avec nos encadrants. C’est pourquoi nous avons mis en place les moyens suivants :

- Pour la communication au sein du groupe : WhatsApp pour tout ce qui est informel.
- Partage des documents : Principalement l’outil Partage de l’IMT Partage Terre Vorace, (https://partage.imt.fr/index.php/s/f4atbGoFYRsG7gz) qui nous permet de partager des documents et des dossiers non seulement entre nous mais aussi avec notre encadrant.
- Pour la communication avec notre encadrant : mail Zimbra, à travers la liste projet-commande-terre-vorace-60@imt-atlantique.fr, que nous avons créée

### 2.4.2. Moyens de communication externe

Nous avons souhaité établir une communication continue avec le client. Pour cela nous utilisons :

- Un groupe WhatsApp, nous permettant de le tenir au courant des avancées du projet, ainsi que de lui demander des outils lorsque cela est nécessaire
- Les mails, pour les premiers échanges (à travers la mailing liste évoquée plus haut)

Nous avons par ailleurs décidé, pendant la première réunion avec le client, de fixer des rendez-vous toutes les deux semaines afin de vérifier que le projet va dans la direction souhaitée.

## Chapitre 3

# Conclusion

En ce début de projet commande entreprise de deuxième année de cycle ingénieur à IMT Atlantique, nous estimons que le lancement s’est bien déroulé : une équipe entièrement motivée et prête à contribuer à la réussite du projet, et une organisation préparée et rigoureuse.

Les attentes du client sont bien cernées, et notre stratégie organisationnelle est claire.

Nom | Actions à court terme
Emilien Wolff | Découverte du modèle 3D fourni par le client et compréhen-sion de l’architecture de conception. Etat de l’art
Louis Albert | Établissement de l’état de l’art du projet
Valentin Rabier | Qualité de l’etat de l’art et du benchmark
Valentin Kayser | Suite des recherches en vue du développement de l’état de l’art
Nathalia Ribeiro de Assis | Gestion des ressources, en assurant le suivi du budget, des matériaux et des outils nécessaires.
Paul Gerbaud | Progression des travaux visant à approfondir l’état de l’art. Poursuite des travaux pour le benchmark
Raphaël Adam | Développement de l’état de l’art. Découverte de l’outil de modélisation.
Sarah Rouyre | Pilotage des ressources, incluant le contrôle du budget, des matériaux et des outils nécessaires

Table 3.1 – Tableau des actions à court terme individuelles

12

## Annexes

13

1. Contrat de projet

## Annexe 1 – Contrat de projet

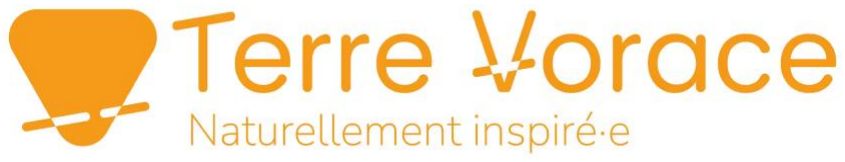
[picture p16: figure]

Équipe projet 60 – Terre Vorace
Membres : Natalia Ribeiro de Assis · Louis Albert · Emilien Wolff · Paul Gerbaud · Valentin Rabier · Valentin Kayser · Sarah Rouyre · Raphaël Adam
Contact : Paul Gerbaud – 06 59 61 94 41
Adresse mail du groupe : projet-commande-terre-vorace-60@imt-atlantique.fr

# Contrat de collaboration – Projet Terre Vorace

## Préambule

Dans le cadre du projet réalisé pour l’entreprise Terre Vorace, les étudiants signataires du présent contrat s’engagent à collaborer de manière structurée et professionnelle. Ce document a pour objectif de définir les rôles de chacun au sein du groupe afin de garantir la bonne organisation et le bon déroulement du projet.

## Article 1 – Parties prenantes

Le projet est mené par un groupe de huit étudiants, dans le cadre d’un travail collectif à destination de l’entreprise Terre Vorace.

## Article 2 – Rôles et responsabilités

Afin d’assurer une répartition claire des tâches, les rôles suivants ont été attribués :

- Emilien Wolff – Pilote du groupe
Responsable de la coordination générale, du suivi de l’avancement et de la bonne réalisation du projet.
- Louis Albert – Responsable de la communication interne
Assure la circulation des informations au sein du groupe et veille à la cohérence des échanges internes.
- Nathalia Ribeiro de Assis– Rouyre Sarah - Responsables de la gestion des ressources Garants de la bonne répartition et de l’utilisation des ressources nécessaires au projet (humaines, matérielles et temporelles).
- Paul Gerbaud – Responsable de la communication externe
Interlocuteur privilégié de l’entreprise Tervoras et garant de la qualité des échanges avec les parties extérieures au groupe.
- Valentin Rabier – Membre actif
Participe à l’ensemble des tâches définies collectivement et apporte son soutien aux responsables de pôles.

1. Contrat de projet

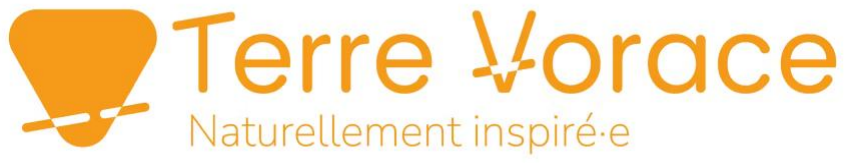
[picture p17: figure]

Équipe projet 60 – Terre Vorace
Membres : Natalia Ribeiro de Assis · Louis Albert · Emilien Wolff · Paul Gerbaud · Valentin Rabier · Valentin Kayser · Sarah Rouyre · Raphaël Adam
Contact : Paul Gerbaud – 06 59 61 94 41
Adresse mail du groupe : projet-commande-terre-vorace-60@imt-atlantique.fr
- Valentin Kaiser – Membre actif
Contribue au développement et à l’exécution des missions, dans le respect des orientations fixées par le groupe.
- Raphaël Adam – Membre actif
Apporte son appui opérationnel et participe activement aux travaux communs du groupe.

(Les autres membres du groupe pourront être désignés sur des missions spécifiques, en fonction des besoins du projet, par décision collective du groupe.)

## Article 3 – Engagements communs

Chaque membre du groupe s’engage à :

- Respecter ses responsabilités et les délais fixés collectivement.
- Participer activement aux réunions de travail.
- Maintenir un esprit de coopération et de respect mutuel.
- Contribuer à la qualité et à la réussite du projet.

## Article 4 – Durée du contrat

Le présent contrat prend effet à compter de sa signature par l’ensemble des membres du groupe et reste valable jusqu’à la remise finale du projet à l’entreprise Terre Vorace.

## Article 5 – Signature des membres

Fait à Nantes, le 19/09/2025. Signatures des membres du groupe :

- Emilien Wolff
- Louis Albert

1. Contrat de projet

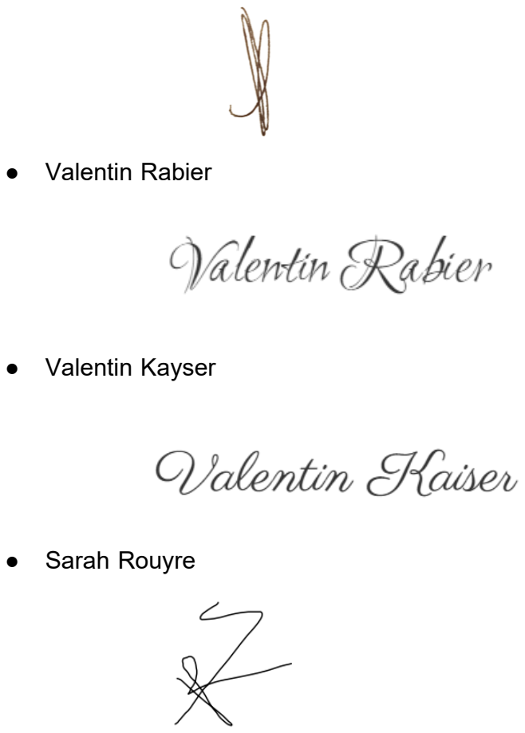
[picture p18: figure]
● Valentin Rabier; ● Valentin Kayser; ● Sarah Rouyre

Équipe projet 60 – Terre Vorace
Membres : Natalia Ribeiro de Assis · Louis Albert · Emilien Wolff · Paul Gerbaud · Valentin Rabier · Valentin Kayser · Sarah Rouyre · Raphaël Adam
Contact : Paul Gerbaud – 06 59 61 94 41
Adresse mail du groupe : projet-commande-terre-vorace-60@imt-atlantique.fr
- Nathalia Ribeiro de Assis
- Paul Gerbaud
- Raphaël Adam

# Bibliographie

[1] Site de Terre Vorace, disponible sur : https://terre-vorace.fr/
[2] Exemple | de | lombricomposteur | empilé | : | https://plus2vers.com/fr/
le-lombricomposteur-city-worms-de-vers-la-terre-test-et-avis/ (https://plus2vers.com/fr/le-lombricomposteur-city-worms-de-vers-la-terre-test-et-avis/)
[3] Guide | du | lombricompostage | CFT | : | https://urbanwormcompany.com/
complete-guide-to-continuous-flow-vermicomposting (https://urbanwormcompany.com/complete-guide-to-continuous-flow-vermicomposting)
[4] Technique | de | lombricomposteur | enterré | aéré | https://ecofarmingdaily.com/build-soil/
soil-inputs/compost/vermiculture-systems (https://ecofarmingdaily.com/build-soil/soil-inputs/compost/vermiculture-systems)
[5] Exemple de CFT industriel automatisé : https://www.wormgear.com/products/cft-systems
[6] Alimentation et conditions de vie des lombrics : https://ccetompkins.org/resources/compost-vermicomposting-brochure-8x11?utm_source=.com (https://ccetompkins.org/resources/compost-vermicomposting-brochure-8x11?utm_source=.com)
[7] Processus de compostage : https://www.fao.org/4/y5104f/y5104f05.htm
[8] Surchauffe du composteur : https://pmc.ncbi.nlm.nih.gov/articles/PMC7084763/
[9] Excès d’humidité : https://www.researchgate.net/publication/241213636_Optimum_moisture_requirement_during_vermicomposting_using_Perionyx_excavatus (https://www.researchgate.net/publication/241213636_Optimum_moisture_requirement_during_vermicomposting_using_Perionyx_excavatus)
[10] Fuite | des | lombrics | : | https://extension.okstate.edu/fact-sheets/
vermicomposting-composting-with-worms.html (https://extension.okstate.edu/fact-sheets/vermicomposting-composting-with-worms.html)
[11] Intrusion | de | nuisibles | : | https://worms.as.ucsb.edu/2015/11/05/
vermicomposting-troubleshooting/ (https://worms.as.ucsb.edu/2015/11/05/vermicomposting-troubleshooting/)
[12] Émanations | d’odeurs | : | https://worms.as.ucsb.edu/2015/11/05/

vermicomposting-troubleshooting/ (https://worms.as.ucsb.edu/2015/11/05/vermicomposting-troubleshooting/)

17

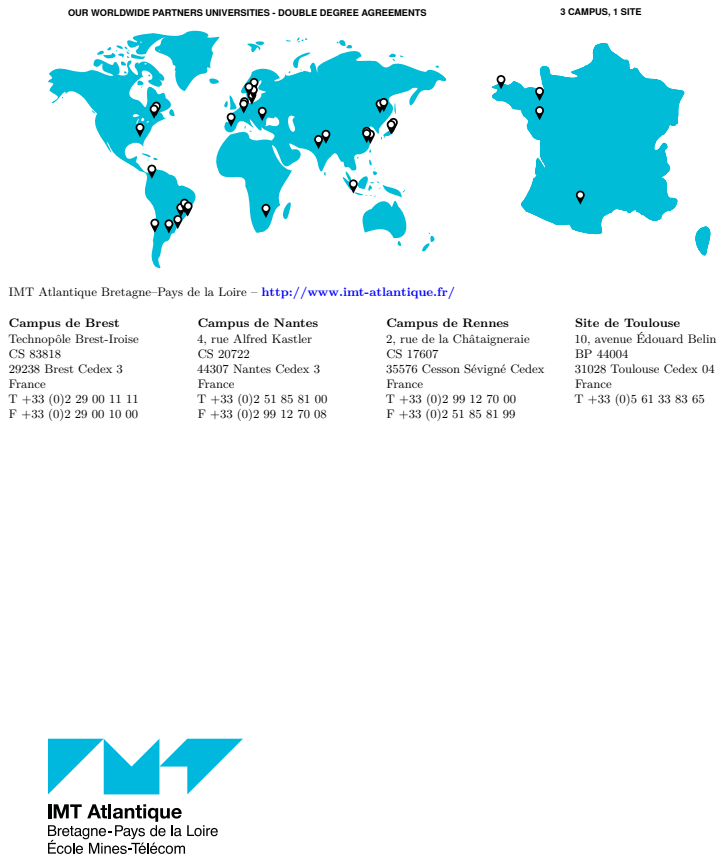
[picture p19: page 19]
OUR WORLDWIDE PARTNERS UNIVERSITIES - DOUBLE DEGREE AGREEMENTS; 3 CAMPUS, 1 SITE; Campus de Brest Technopôle Brest-Iroise CS 83818 29238 Brest Cedex 3 France T +33 (0)2 29 00 11 11 F +33 (0)2 29 00 10 00; Campus de Nantes 4, rue Alfred Kastler CS 20722 44307 Nantes Cedex 3 France T +33 (0)2 51 85 81 00 F +33 (0)2 99 12 70 08

IMT Atlantique Bretagne–Pays de la Loire – http://www.imt-atlantique.fr/

Campus de Rennes
2, rue de la Châtaigneraie
35576 Cesson Sévigné Cedex
France

Site de Toulouse
10, avenue Édouard Belin
31028 Toulouse Cedex 04

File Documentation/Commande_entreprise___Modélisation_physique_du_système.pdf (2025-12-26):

X

Modélisation physique du système - GROUPE 60 Projet Commande Entreprise - parcours ingénieur A2 FISE

## Projet Commande Entreprise :

## Système d’aération d’un milieu fermé

## en lombricompostage autonome

Destinataires : FRISCOURT François, D’HERBEMONT Arthur Relecteurs : RABIER Valentin


Date d’édition : 23 octobre 2025 Version : V2

Wolff Emilien

Gerbaud Paul

Albert Louis
Kayser Valentin
Rabier Valentin

Rouyre Sarah
Adam Raphaël

Ribeiro de Assis Nathalia

Tuteur école : D’Herbemont Arthur Tuteur entreprise : Friscours François

IMT Atlantique
Projet Commande Entreprise
Campus de Nantes — IMT Atlantique 4, rue Alfred Kastler — La Chantrerie CS 20722
44307 Nantes Cedex 3
Téléphone : +33 (0)2 51 85 81 00 URL : www.imt-atlantique.fr

Liste des tableaux

### Sommaire

1. Mise en équation du problème | 2
1.1. Modélisation thermique du lombricomposteur | | 2
1.1.1. Description des flux thermiques | | 2
1.2. Détermination expérimentale et estimation des paramètres thermiques | | 4
1.2.1. Puissance thermique générée par le composte | | 4
1.2.2. Capacité thermique du compost | | 4
1.2.3. Ordres de grandeur retenus | | 5
2. Analyse quantitative | 6
2.1. Analyse quantitative du problème | | 6
2.1.1. Estimations numériques des termes du bilan | | 6
2.1.2. Simplification de l’équation | | 6
2.1.3. Application numérique | | 7
Annexes | 8
Références | 9

### Liste des figures

### Liste des tableaux

1.1. Définition des principales variables thermiques du modèle | | 3
Modélisation physique du système | 1/9

## Chapitre 1

# Mise en équation du problème

Dans cette section, on établit d’abord le modèle thermique complet du lombricomposteur, intégrant l’ensemble des sources et transferts de chaleur internes (activité microbienne) et externes (rayonnement solaire, convection, conduction, ventilation, évaporation). Une analyse quantitative des ordres de grandeur permettra ensuite de simplifier cette équation en négligeant certains flux jugés mineurs.

### 1.1. Modélisation thermique du lombricomposteur

### 1.1.1. Description des flux thermiques

Le schéma ci-dessous illustre les principaux flux de chaleur agissant sur le lombricomposteur. La puissance Q˙
gen correspond à la chaleur produite par l’activité microbienne du compost. Une partie de cette énergie est transmise vers l’extérieur par conduction et convection à travers les parois, regroupées dans le terme Q˙

cond+conv. Le flux Q˙
vent traduit les échanges liés au renouvellement d’air : l’air entrant à Tin ressort plus chaud à Tout, emportant une quantité de chaleur. Le flux Q˙
solaire représente l’apport énergétique dû au rayonnement solaire absorbé par la surface du composteur, tandis que Q˙ evap correspond à la chaleur consommée par l’évaporation de l’eau contenue dans le compost.

;

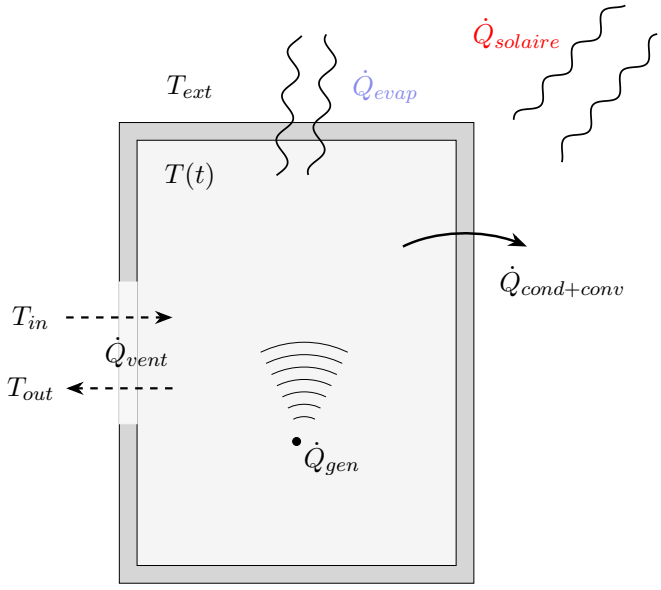
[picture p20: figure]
gen; Text; cond+conv; Tin; Tout; vent; evap; solaire

Définition des variables

Résistances thermiques et conductance globale

La résistance thermique équivalente à travers les parois est donnée par :

Rparoi =

1

hinA

+

e
kA +

1

houtA

(1.1)

2

1.1. Modélisation thermique du lombricomposteur

T(t) Température intérieure (K)
Text | Température extérieure (K)
A | Surface d’échange (m² )
e | Épaisseur de la paroi (m)
k | Conductivité thermique (W·m⁻¹·K⁻¹ )
hin | Coeff. convection interne (W·m⁻²·K⁻¹ )
hout | Coeff. convection externe (W·m⁻²·K⁻¹
)
ε | Émissivité (–)
σ | Constante de Stefan–Boltzmann (5.67 × 10⁻⁸ W·m⁻²·K⁻⁴ )
m | Masse totale (kg)
cp | Capacité thermique massique (J·kg⁻¹·K⁻¹
)
C = mcp Capacité thermique (J·K⁻¹
)
Q˙
gen | Puissance générée (W)
Q˙
sol | Flux solaire (W)
m˙ air | Débit d’air (kg·s

−1
)
Tin | Température d’entrée (K)
m˙ v | Débit de vapeur (kg·s

−1
)
Lv | Chaleur latente (J·kg⁻¹
)

Table 1.1 – Définition des principales variables thermiques du modèle.

Le rayonnement externe peut être modélisé par un coefficient équivalent :

hrad = 4 ε σ T³
(1.2)

On peut alors corriger la convection externe :

hout,eq = hout + hrad | (1.3)

et recalculer :
R =

1

hinA

+

e
kA +

1

hout,eqA

(1.4)

La conductance thermique globale vaut : G =

1
R

(1.5)

Bilan d’énergie global

Le bilan d’énergie du système (masse quasi-isotherme) s’écrit :

C

dT
dt = Q˙

gen + Q˙
sol − G (T − Text) − m˙ aircp(T − Tin) − Lv m˙ v | (1.6)

Régime stationnaire

En régime permanent (dT /dt = 0), la température interne est (Tss = Tstationnary state) :

Tss =

Text
R

+ ˙maircpTin + Q˙

gen + Q˙
sol − Lvm˙ v

1
R

+ ˙maircp

(1.7)

Condition de stabilité thermique (Tss ≤ T

⋆
)

Dimensionnement de la ventilation :

Pour imposer une température maximale T

⋆
, on obtient :

m˙ air ≥

Q˙

gen + Q˙
sol − Lvm˙ v −

T

⋆ − Text

R
cp(T⋆ − Text)

(1.8)

Dimensionnement de l’isolation :

Si le débit d’air est imposé, la résistance maximale admissible vérifie :

1
R

≥

Q˙

gen + Q˙
sol − Lvm˙ v − m˙ aircp(T

⋆ − Tin)

T⋆ − Text

(1.9)

1.2. Détermination expérimentale et estimation des paramètres thermiques

Temps de réponse thermique

Le comportement dynamique est du premier ordre, avec une constante de temps :

τ =

C
1
R

+ ˙maircp

(1.10)

Ainsi, la condition fondamentale pour additionner des résistances thermiques en série est que le flux de chaleur traversant chaque résistance soit identique et unidirectionnel.

### 1.2. Détermination expérimentale et estimation des paramètres thermiques

### 1.2.1. Puissance thermique générée par le composte

La chaleur dégagée par le compost provient de la dégradation biologique de la matière organique, réaction exothermique :
Matière organique + O2 −→ CO2 + H2O + chaleur

Cette chaleur correspond à la puissance thermique Q˙
gen produite par les micro-organismes. Pour la déterminer expérimentalement, on peut placer un échantillon de compost dans une boîte adiabatique, de sorte que les échanges thermiques avec l’extérieur soient négligeables. Si la capacité thermique totale du système est C, la variation de température observée dT
dt permet d’évaluer la puissance générée par :

Q˙
gen = C

dT
dt | (1.11)

où C est la capacité thermique totale du compost (et éventuellement de la boîte). Cette méthode suppose une homogénéité thermique et une bonne isolation du dispositif, de façon à négliger les pertes par conduction, convection ou rayonnement.

### 1.2.2. Capacité thermique du compost

Le compost est un milieu poreux humide composé principalement d’eau et de matière organique sèche (cellulose, lignine, protéines, minéraux). On peut estimer sa capacité thermique massique cp,compost à partir d’une moyenne pondérée entre la phase aqueuse et la phase sèche :

cp,compost = xeau cp,eau + (1 − xeau) cp,matière sèche | (1.12)

où :
- xeau est la fraction massique d’eau (généralement comprise entre 0.6 et 0.8),
- cp,eau ≃ 4180 J·kg⁻¹·K

−1
,
- cp,matière sèche est la capacité thermique massique de la matière sèche.

D’après les données du CRC Handbook of Chemistry and Physics, de Perry & Green (Chemical Engineers’ Handbook) [1] et de la FAO, les principaux constituants de la matière organique (cellulose, lignine, protéines, lipides) présentent des capacités thermiques comprises entre 1500 et 2000 J·kg⁻¹·K

−1
| . On peut ainsi
retenir :
cp,matière sèche ≈ 1700 J·kg⁻¹·K

−1

Pour un compost typique contenant 70% d’eau (xeau = 0.7), on obtient :

cp,compost = 0.7 × 4180 + 0.3 × 1700 ≈ 3560 J·kg⁻¹·K

−1

La capacité thermique totale du compost s’en déduit par :

C = m cp,compost | (1.13)

où m est la masse totale de compost considérée.
Cette valeur est cohérente avec celles observées expérimentalement pour des composts humides et permet d’évaluer correctement les bilans énergétiques du lombricomposteur.

1.2. Détermination expérimentale et estimation des paramètres thermiques

### 1.2.3. Ordres de grandeur retenus

Grandeur | Symbole | Valeur typique
Fraction massique d’eau | xeau | 0.6 – 0.8
Capacité thermique de l’eau | cp,eau | 4180 J·kg⁻¹·K⁻¹
Capacité thermique matière sèche | cp,matière sèche | 1700 J·kg⁻¹·K⁻¹
Capacité thermique compost | cp,compost | 3000 – 4000 J·kg⁻¹·K⁻¹
Capacité thermique totale (10 kg) C | ∼ 3.5 × 10⁴ J·K⁻¹

Ces valeurs sont utilisées pour le dimensionnement thermique et la modélisation du lombricomposteur, en cohérence avec les données issues du CRC Handbook, de Perry & Green et des publications techniques de la FAO.

## Chapitre 2

# Analyse quantitative

### 2.1. Analyse quantitative du problème

### 2.1.1. Estimations numériques des termes du bilan

Apport solaire Q˙
solaire.

On prend une surface effectivement exposée A⊙ = 0,120 m²
, une absorptivité moyenne α = 0,5 (bois/plastique clair) et une irradiance intérieure diffuse G = 50 W m⁻² :

Q˙
solaire = α A⊙ G = 0,5 × 0,12 × 50 = | 3 W | .

Refroidissement par évaporation Q˙
evap = Lv m˙ v.

Avec Lv ≃ 2,45 × 10⁶ J kg⁻¹
et une perte d’eau mesurée ou estimée en intérieur à 20–50 mL/j (HR 60–80%) :

m˙ v =

∆m
86400

⇒

20 mL/j (0,020 kg/j) ⇒ Q˙
evap ≈ | 0,6 W | ,
50 mL/j (0,050 kg/j) ⇒ Q˙
evap ≈ | 1,4 W | .

Chaleur générée par le compost Q˙
gen.

Méthode adiabatique : depuis C

dT
dt = Q˙
gen. Pour une pente mesurée typique en régime actif doux dT /dt = (0,6 à 1,4) × 10⁻³ K s⁻¹
:

Q˙
gen = C

dT
dt

≈ (3,6 × 10⁴

) × (0,6 à 1,4) × 10⁻³ ⇒ | 22 à 50 W | .

Lecture rapide.

Q˙

gen ∼ 20–50 W | ≫ | Q˙
solaire ∼ 3 W | ≳ | Q˙
evap ∼ 0,6–1,4 W

En intérieur et HR 60–80%, l’évaporation est faible et l’apport solaire diffus modéré ; la puissance microbienne reste le terme dominant.

### 2.1.2. Simplification de l’équation

Ainsi, l’équation (1.6) se simplifie en :

C

dT
dt = Q˙
gen − G (T − Text) − m˙ aircp(T − Tin) | (2.1)

Le débit d’air minimal pour assurer une température inférieur donc à T

⋆
est :

m˙ air ≥

Q˙
gen −

T

⋆ − Text

R
cp(T⋆ − Text)

(2.2)

6

2.1. Analyse quantitative du problème

### 2.1.3. Application numérique

Principe.

En imposant T = T

⋆ = 30řC, le débit massique minimal est

m˙

min
air =

Q˙
gen −

T

⋆ − Text

R
cp,air (T⋆ − Text)
(si le numérateur > 0). | (2.3)

Paramètres géométriques et de transfert.

Dimensions de la boîte : L = 0,35 m, W = 0,35 m, H = 0,70 m. Surface totale d’échange :

A = 2 (LW + LH + W H) = 2 (0,35×0,35 + 0,35×0,70 + 0,35×0,70) = 1,225 m² .

Épaisseur de paroi e = | 6 mm | = 0,006 m, conductivité k = 0,20 W m⁻¹ K

−1
. Convection interne hin = 5 W m⁻² K

−1
, externe hout = 10 W m⁻² K

−1
. Températures : T
⋆ = 30 ◦C, Text = | 21 ◦C | (∆T = 9 K). Air :
cp,air ≃ 1005 J kg⁻¹ K

−1

. Puissance biologique supposée : Q˙ gen = 30 W.

Résistance thermique globale.

R =

1

hinA

+

e
kA +

1

houtA

=

1
5 × 1,225

+

0,006
0,20 × 1,225

+

1
10 × 1,225
= | 0,269 KW⁻¹
. | (2.4)

Débit minimal requis.

Avec (2.3) :

m˙

min
air =

Q˙
gen −

∆T
R
cp,air ∆T

=

30 −

9
0,269
1005 × 9

≈

30 − 33,4
9045

< 0.

Le numérateur étant négatif, aucun débit d’air n’est requis pour tenir T ≤ 30 ◦C dans ces conditions : les pertes par parois (∆T /R ≈ 33,4 W) suffisent à évacuer la puissance microbienne supposée (30 W).

### Annexes

8

# Bibliographie

[1] CRC Handbook of Chemistry and Physics https://webdelprofesor.ula.ve/ciencias/isolda/libros/handbook.pdf (https://webdelprofesor.ula.ve/ciencias/isolda/libros/handbook.pdf)

9

OUR WORLDWIDE PARTNERS UNIVERSITIES - DOUBLE DEGREE AGREEMENTS; 3 CAMPUS, 1 SITE; Campus de Brest Technopôle Brest-Iroise CS 83818 29238 Brest Cedex 3 France T +33 (0)2 29 00 11 11 F +33 (0)2 29 00 10 00; Campus de Nantes 4, rue Alfred Kastler CS 20722 44307 Nantes Cedex 3 France T +33 (0)2 51 85 81 00 F +33 (0)2 99 12 70 08

IMT Atlantique Bretagne–Pays de la Loire – http://www.imt-atlantique.fr/

Campus de Rennes
2, rue de la Châtaigneraie
35576 Cesson Sévigné Cedex
France

Site de Toulouse
10, avenue Édouard Belin
31028 Toulouse Cedex 04

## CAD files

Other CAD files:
Modélisations 3D/capuchon.f3d
Modélisations 3D/logo imt.f3d
Modélisations 3D/logo terre vorace.f3d
